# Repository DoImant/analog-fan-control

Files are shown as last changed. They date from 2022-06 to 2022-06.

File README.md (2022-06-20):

# Description:

This fan control circuit was realized with an LM317 voltage regulator. The circuit is suitable for fans that cannot be regulated via PWM (2 or 3-pin).
The maximum operating voltage is 12V. An NTC 10K 3950 (1%) with JST XH cable connector is used for temperature measurement.
The circuit board is equipped with a four-pin fan connector. If a fan with three pins is connected, the signal for the fan speed can be picked off at the free fourth pin (S. out) of the connector plug.

## Temperature setting:
Turn RV1 all the way to the right. Bring NTC to body temperature (hold with your fist), wait a little and then RV1
turn to the left until the fan starts to rotate. From the point three more half turns further.

Turn RV2 until the voltage at VAdjust is 4.7 to 4.8 volts.

With this setting method, the fan starts to run from around 36°C. As the temperature rises, the fan speed increases up to the maximum speed at around 70°C. If the temperature drops to approx. 26°C, the fan is switched off again.

## Pictures

First test setup on a breadboard
Breadboard setup

PCB (front)
PCB front

PCB back
PCB back

## circuit diagram
[circuit diagram](https://github.com/DoImant/Stuff/blob/main/Analog_fan_control/Luefter-Steuerung-Analog-V2.pdf)

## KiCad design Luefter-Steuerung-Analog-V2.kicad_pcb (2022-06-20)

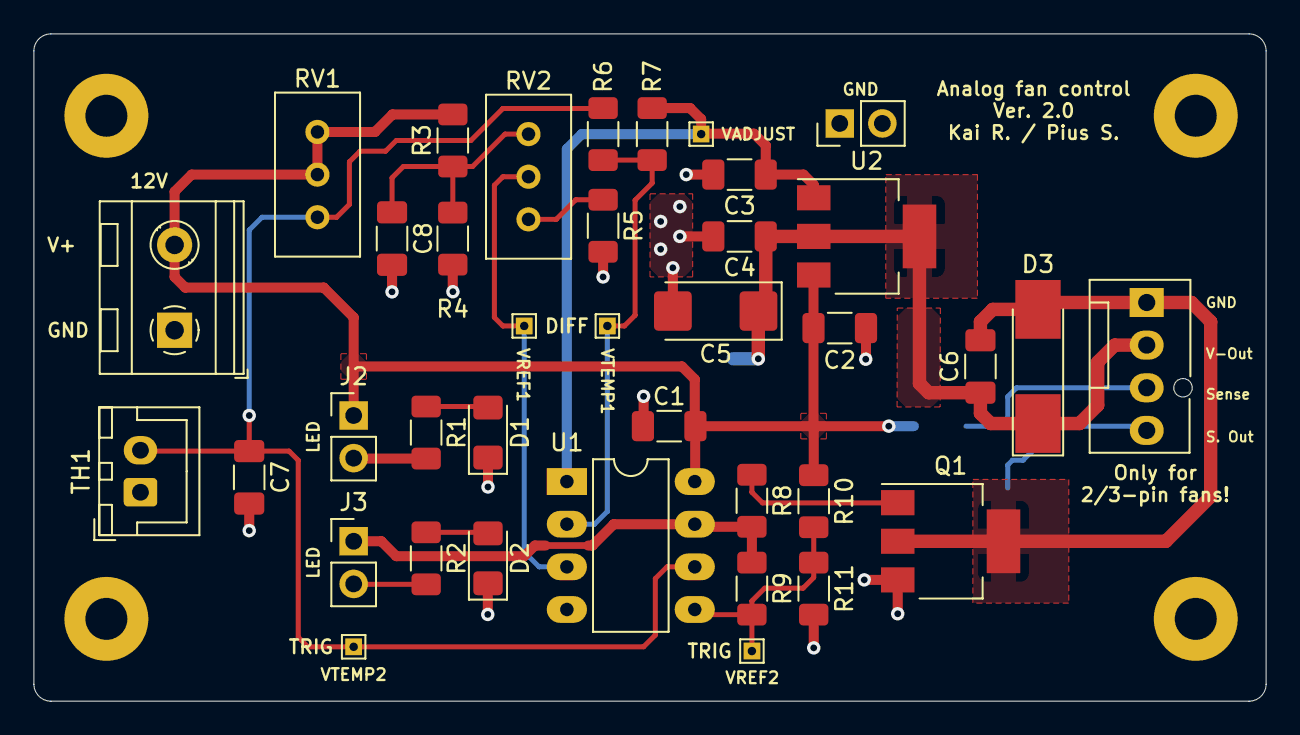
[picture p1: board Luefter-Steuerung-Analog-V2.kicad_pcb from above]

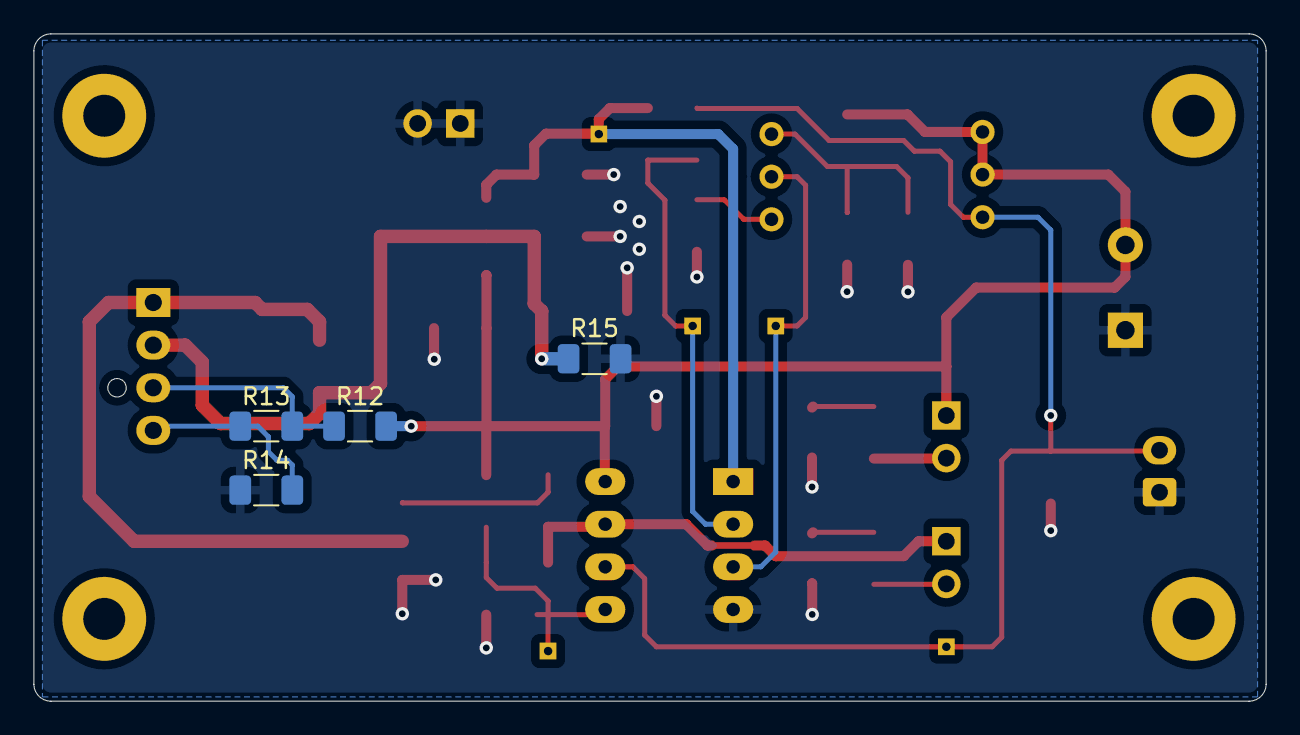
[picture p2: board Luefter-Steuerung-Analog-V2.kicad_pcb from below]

Board: 2 copper layers, 73.4 x 39.8 mm, 45 parts (4 on the bottom side), 19 nets.

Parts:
C1, C2, C4, C6: 100n; C_1206_3216Metric_Pad1.33x1.80mm_HandSolder
C3: 1u; C_1206_3216Metric_Pad1.33x1.80mm_HandSolder
C5: 10u; CP_EIA-6032-28_Kemet-C_Pad2.25x2.35mm_HandSolder
C7, C8: 10n; C_1206_3216Metric_Pad1.33x1.80mm_HandSolder
D1, D2: LED; LED_1206_3216Metric_Pad1.42x1.75mm_HandSolder
D3: 1N4001; D_MELF_Handsoldering
H1, H2, H3, H4: MountingHole; MountingHole_2.5mm_Pad
J1: Conn_01x02; TerminalBlock_RND_205-00232_1x02_P5.08mm_Horizontal
J2, J3: Conn_01x02; PinHeader_1x02_P2.54mm_Vertical
J4: Conn_01x04_Male; FanPinHeader_1x04_P2.54mm_Vertical
Q1: BCP56; SOT-223-3_TabPin2
R1, R2: 15k; R_1206_3216Metric_Pad1.30x1.75mm_HandSolder
R3, R10: 47k; R_1206_3216Metric_Pad1.30x1.75mm_HandSolder
R4, R15: 100k; R_1206_3216Metric_Pad1.30x1.75mm_HandSolder
R5: 82k; R_1206_3216Metric_Pad1.30x1.75mm_HandSolder
R6: 33k; R_1206_3216Metric_Pad1.30x1.75mm_HandSolder
R7: 68k; R_1206_3216Metric_Pad1.30x1.75mm_HandSolder
R8, R13, R14: 10k; R_1206_3216Metric_Pad1.30x1.75mm_HandSolder
R9: 270k; R_1206_3216Metric_Pad1.30x1.75mm_HandSolder
R11: 56k; R_1206_3216Metric_Pad1.30x1.75mm_HandSolder
R12: 4k7; R_1206_3216Metric_Pad1.30x1.75mm_HandSolder
RV1: 10k; Potentiometer_Bourns_3296W_Vertical
RV2: 20k; Potentiometer_Bourns_3296W_Vertical
TH1: 10k; JST_XH_B2B-XH-A_1x02_P2.50mm_Vertical
TP1, TP2, TP3, TP4, TP5: TestPoint; TestPoint_THTPad_1.0x1.0mm_Drill0.5mm
U1: LM358; DIP-8_W7.62mm_LongPads
U2: LM317_SOT-223; SOT-223-3_TabPin2

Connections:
+12V: C1.1, C2.1, J1.2, J2.1, R3.1, R10.1, R12.1, RV1.1, RV1.2, U1.8, U2.3
/SIG-Ref: C8.1, R3.2, R4.1, RV2.1
/SIG_Adjust: C3.1, R7.1, TP3.1, U1.1, U2.1
/SIG_REF(+): RV2.2, TP2.1, U1.3
/SIG_REF_TRIG: R9.2, R10.2, R11.1, TP4.1, U1.5
/SIG_TEMP(-): R6.2, R7.2, TP1.1, U1.2
/SIG_Temp: C7.1, R6.1, RV1.3, TH1.2, TP5.1, U1.6
/Sense: J4.3, R12.2, R13.1
/Sense_Out: J4.4, R13.2, R14.1
/TRIG_ON_OFF: J3.1, R8.2, R9.1, U1.7
/V-OUT: C4.1, C5.1, C6.1, D3.1, J4.2, R15.1, U2.2
GND: C1.2, C2.2, C3.2, C4.2, C5.2, C7.2, C8.2, D1.1, D2.1, J1.1, Q1.3, R4.2, R5.2, R11.2, R14.2, R15.2, TH1.1, U1.4
unnamed: C6.2, D3.2, J4.1, Q1.2
unnamed: D1.2, R1.1
unnamed: D2.2, R2.1
unnamed: J2.2, R1.2
unnamed: J3.2, R2.2
unnamed: Q1.1, R8.1
unnamed: R5.1, RV2.3
